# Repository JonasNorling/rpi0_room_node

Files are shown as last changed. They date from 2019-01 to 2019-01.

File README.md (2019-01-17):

# Raspberry Pi Zero Room Board

## Features

### IR transmitter and receiver

Pinout:
 - 11 - BMC17 - IR TX
 - 12 - BCM18 - IR RX

These should be the default pins for the lirc_rpi module.
Reference: https://github.com/Irdroid/Irdroid-Rpi

### One-wire

Pinout:
 - 7 - BCM4 - one-wire signal

This should be the default pin for the w1-gpio module.
Reference: https://pinout.xyz/pinout/1_wire#

### RFM69 module

Pinout:
 - 19 - SPI0 MOSI - MOSI
 - 21 - SPI0 MISO - MISO
 - 23 - SPI0 SCLK - SCLK
 - 24 - SPI0 CE0 - chip select
 - 22 - BCM25 - DIO 0
 - 18 - BCM24 - DIO 1
 - 16 - BCM23 - DIO 2
 - 15 - BCM22 - RST

References:

#### https://github.com/hallard/LoRasPI/blob/master/README.md
 - GPIO22 - RST
 - GPIO25 - DIO0 or DIO1 or DIO2
 - GPIO23 - LED
 - GPIO24 - LED

#### http://wiki.dragino.com/index.php?title=Lora/GPS_HAT
 - GPIO7 - DIO0
 - GPIO0 - RST

#### https://github.com/PiInTheSky/pits-hardware/blob/master/PiLoraGatewayV2.5.pdf
 - GPIO5 - data LED
 - GPIO24 - DIO5
 - GPIO25 - DIO0

https://github.com/kobuki/RFM69OOK/blob/master/RFM69OOK.cpp
https://github.com/SevenW/embapps/tree/master/ArduinoRFM69

### LEDs

 - 3 - BCM2 - LED1
 - 5 - BCM3 - LED2
 - 13 - BCM27 - LED3
 - 29 - BCM5 - LED red
 - 31 - BCM6 - LED green
 - 32 - BCM12 - LED blue

## Things to fix in next revision

- Add protection resistor on DIO 2 -- it can be bidirectional.
- Preferably resistors on all DIOs
- Add current limiting resistor on one-wire supply pin -- the devices don't draw much current at all and it makes sense to protect the RPi's supply from whatever environment the one-wire sensors are in.

- SMA connector footprint is too wide for my connector from Electrokit
- RFM69 footprint is too wide
- SMA sits in a bad position for a RPi3

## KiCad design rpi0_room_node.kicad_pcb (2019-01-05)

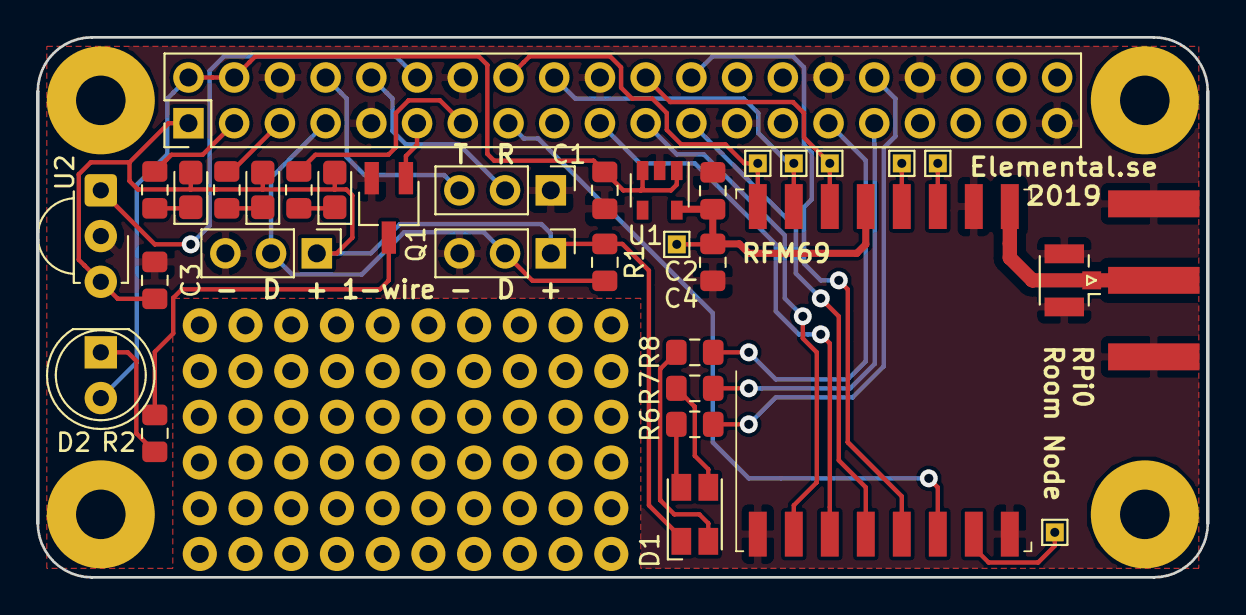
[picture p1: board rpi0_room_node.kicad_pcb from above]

Board: 2 copper layers, 65.0 x 30.0 mm, 38 parts (0 on the bottom side), 35 nets.

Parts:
AE1: SMA; SMA_Amphenol_132289_EdgeMount
AE2: U.FL; U.FL_Hirose_U.FL-R-SMT-1_Vertical
C1, C2, C4: C; C_0805_2012Metric_Pad1.15x1.40mm_HandSolder
C3: 1u; C_0805_2012Metric_Pad1.15x1.40mm_HandSolder
D1: ASMB-MTB0-0A3A2; LED_Avago_PLCC4_3.2x2.8mm_CW
D2: CQY99; LED_D5.0mm_IRGrey
D3, D4, D5: LED; LED_0805_2012Metric_Castellated
H1, H2, H3, H4: MountingHole; hole_2.75
J1: Raspberry Pi; PinHeader_2x20_P2.54mm_Vertical
J2, J3, J4: Conn_01x03; PinHeader_1x03_P2.54mm_Vertical
Q1: PDTC123Y; SC-59_Handsoldering
R1: 4k7; R_0805_2012Metric_Pad1.15x1.40mm_HandSolder
R2, R3, R4, R5, R6, R7, R8: R; R_0805_2012Metric_Pad1.15x1.40mm_HandSolder
TP1, TP2, TP3, TP4, TP5, TP6, TP7: TestPoint; TestPoint_THTPad_1.0x1.0mm_Drill0.5mm
U1: AP2210K-3.3; SOT-23-5
U2: TSOP382xx; Vishay_MINICAST-3Pin
U3: RFM69HCW; HOPERF_RFM69HW

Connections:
+3V3: C3.1, D1.1, D3.2, D4.2, D5.2, J1.1, J2.1, J4.1, R1.1, U2.3
+5V: C1.1, D2.2, J1.2, J1.4, U1.1, U1.3
/ANT: AE1.1, AE2.1, U3.9
/CE0: J1.24, U3.5
/IRRX: J1.12, U2.1
/IRTX: J1.11, Q1.1
/LED1: J1.3, R3.1
/LED2: J1.5, R4.1
/LED3: J1.13, R5.1
/LEDB: J1.32, R6.1
/LEDG: J1.31, R7.1
/LEDR: J1.29, R8.1
/MISO: J1.21, U3.2
/MOSI: J1.19, U3.3
/ONEWIRE: J1.7, J2.2, J4.2, R1.2
/RFM_DIO0: J1.22, TP6.1, U3.14
/RFM_DIO1: J1.18, TP5.1, U3.15
/RFM_DIO2: J1.16, TP4.1, U3.16
/RFM_DIO3: TP3.1, U3.11
/RFM_DIO4: TP2.1, U3.12
/RFM_DIO5: TP1.1, U3.7
/RFM_RST: J1.15, U3.6
/RXD: J1.10, J3.2
/SCLK: J1.23, U3.4
/TXD: J1.8, J3.3
GND: AE1.2, AE2.2, C1.2, C2.2, C3.2, C4.2, J1.6, J1.9, J1.14, J1.20, J1.25, J1.30, J1.34, J1.39, J2.3, J3.1, J4.3, Q1.2, U1.2, U2.2, U3.1, U3.8, U3.10
unnamed: D1.2, R6.2
unnamed: D1.3, R7.2
unnamed: D1.4, R8.2
unnamed: D2.1, R2.1
unnamed: D3.1, R3.2
unnamed: D4.1, R4.2
unnamed: D5.1, R5.2
unnamed: Q1.3, R2.2
VDDA: C2.1, C4.1, TP7.1, U1.5, U3.13

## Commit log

2019-01-02 Starting out
    [rpi0_room_node.kicad_pcb, rpi0_room_node.sch]
2019-01-02 Basic PCB layout
    [rpi0_room_node.kicad_pcb, rpi0_room_node.sch]
2019-01-02 Add u.fl and second onewire header
    [rpi0_room_node.kicad_pcb, rpi0_room_node.sch]
2019-01-02 Add prototyping area
    [rpi0_room_node.kicad_pcb, rpi0_room_node.sch]
2019-01-02 Clean up silkscreen
    [rpi0_room_node.kicad_pcb, rpi0_room_node.sch]
2019-01-02 Silkscreen improvements
    [rpi0_room_node.kicad_pcb]
2019-01-05 Add test points, DIO 2
    [rpi0_room_node.kicad_pcb, rpi0_room_node.sch]
2019-01-05 Add testpoint, clean up
    [rpi0_room_node.kicad_pcb, rpi0_room_node.sch]
2019-01-05 Gerber options
    [rpi0_room_node.kicad_pcb]
2019-01-17 rev.A gerbers
    [rpi0_room_node-B.Cu.gbl, rpi0_room_node-B.Mask.gbs, rpi0_room_node-B.SilkS.gbo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]
2019-01-17 Component values and errata
    [rpi0_room_node.sch]
